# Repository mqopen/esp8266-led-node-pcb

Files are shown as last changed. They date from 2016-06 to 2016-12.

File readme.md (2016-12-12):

# ESP8266 LED Node PCB

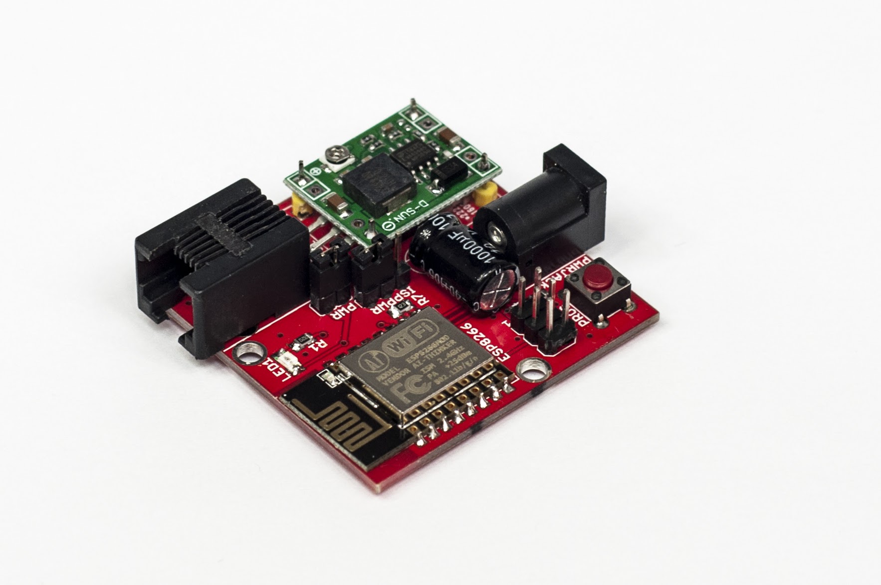
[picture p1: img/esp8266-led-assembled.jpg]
Assembled node


## Features

 - Powered by mini DC-DC power supply module ([LM2596](http://www.ti.com/lit/ds/symlink/lm2596.pdf) chip).
 - 5.5 mm center positive jack.
 - On-board programming connector.
 - Programming push button.
 - Jumper for enabling power supply module.
 - Notification LED.
 - Intended to be manufactured by [dirtypcbs.com](http://dirtypcbs.com/).
 - AVR like ISP header for in circuit programming.
 - MOSFET transistor. 
 - RJ-11 connector for connecting LED strips.

## Images

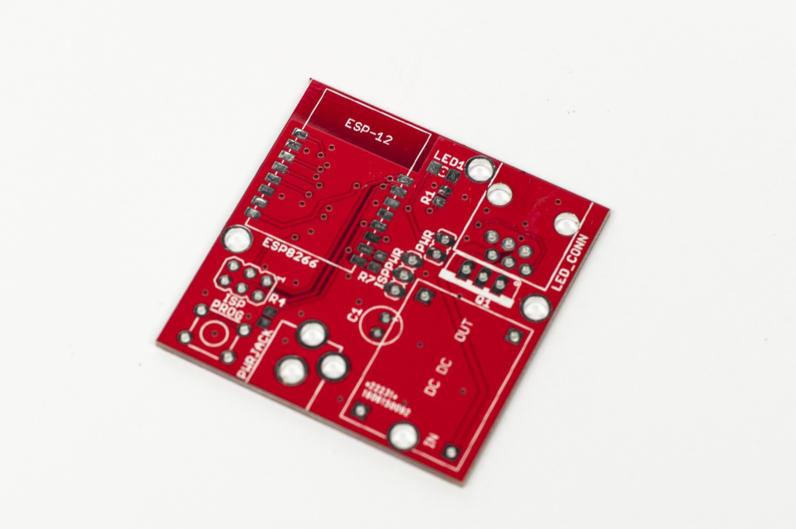
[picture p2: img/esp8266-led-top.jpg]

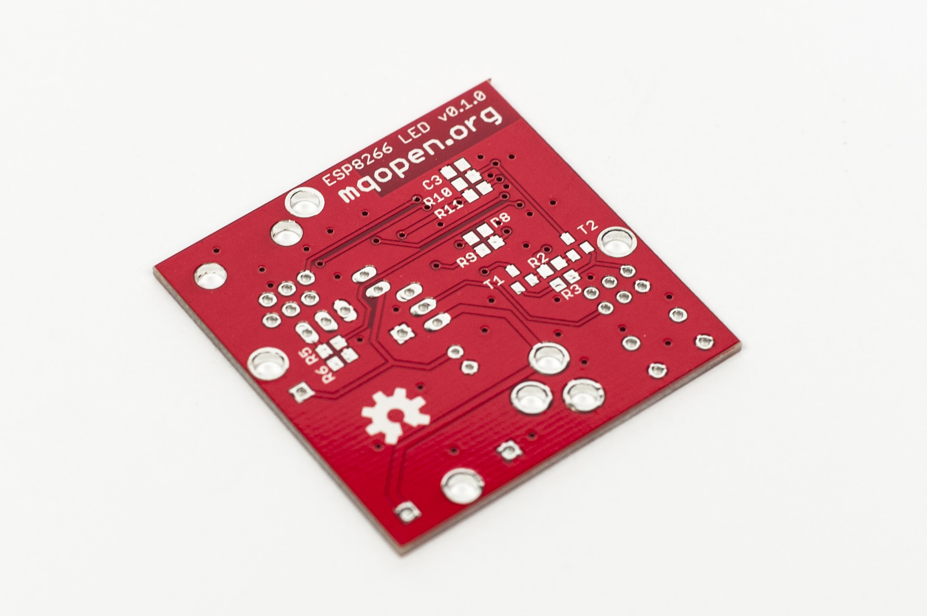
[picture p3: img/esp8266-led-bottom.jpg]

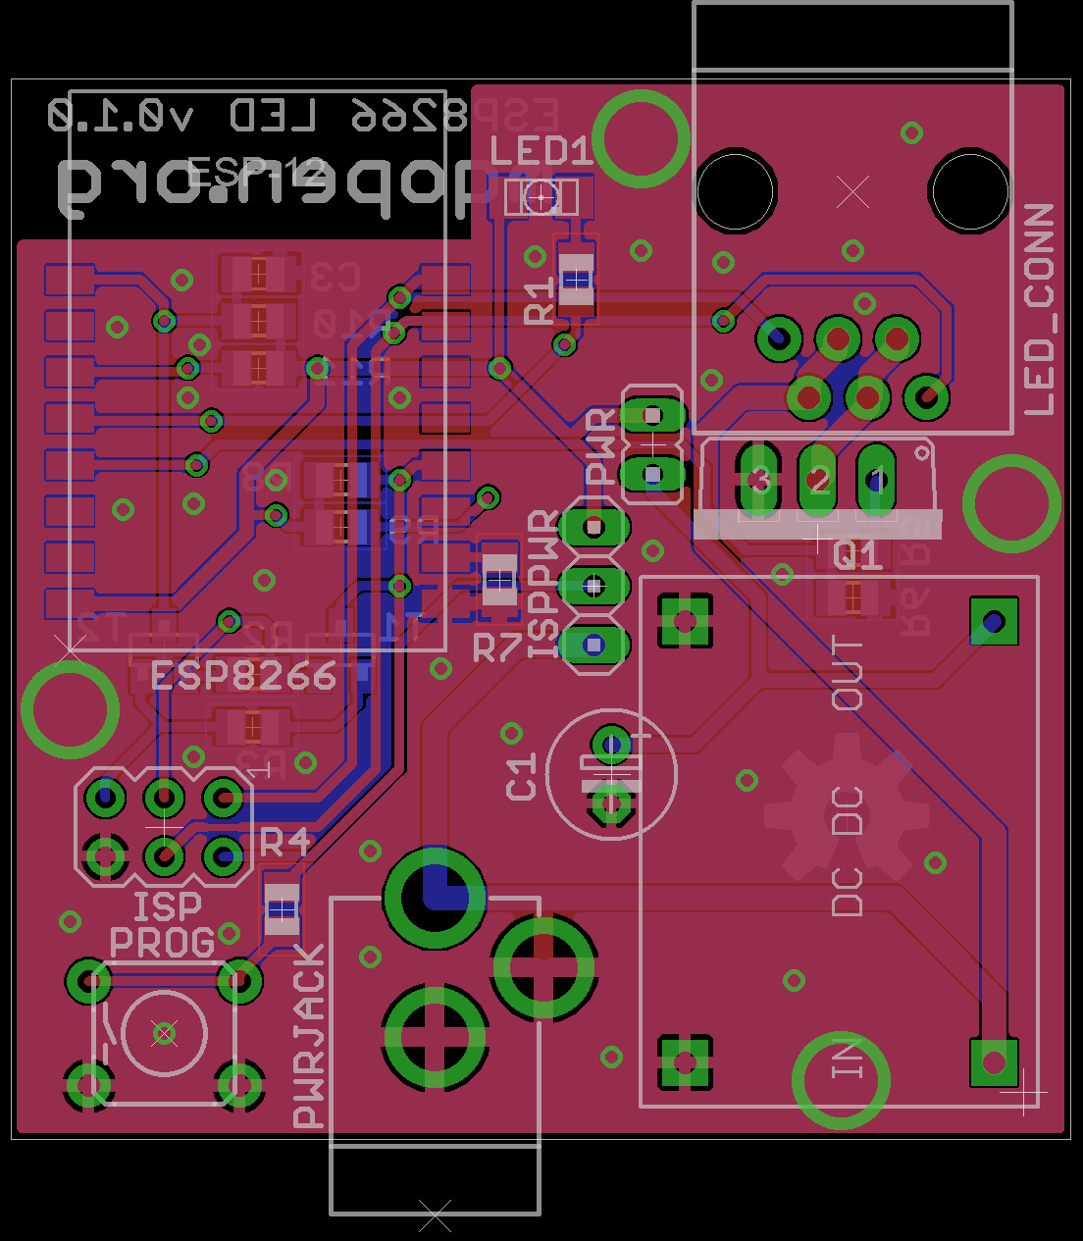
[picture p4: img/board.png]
Board design


## Get board

You can order PCB on this [link](http://dirtypcbs.com/store/designer/details/9988/967/esp8266-led-v0-1-0-zip).

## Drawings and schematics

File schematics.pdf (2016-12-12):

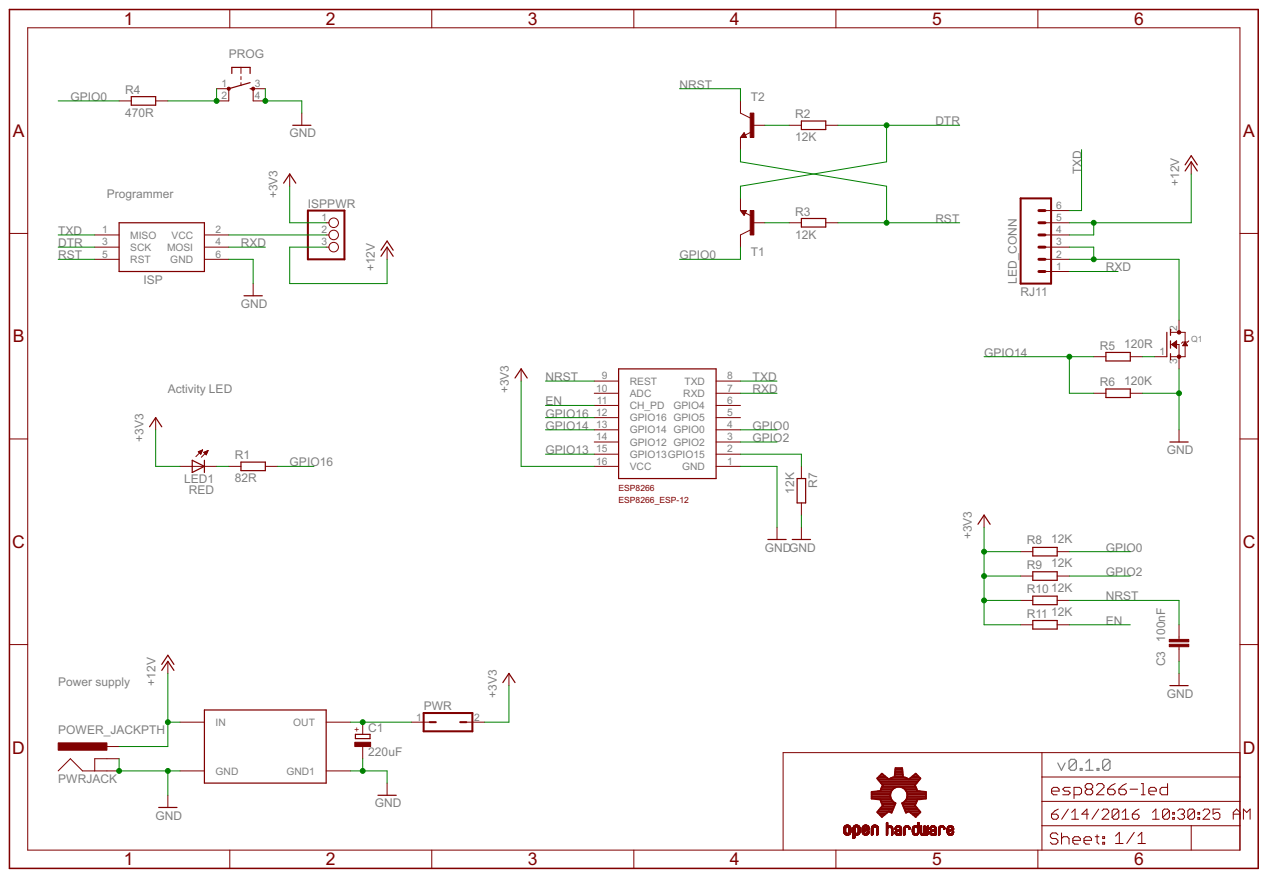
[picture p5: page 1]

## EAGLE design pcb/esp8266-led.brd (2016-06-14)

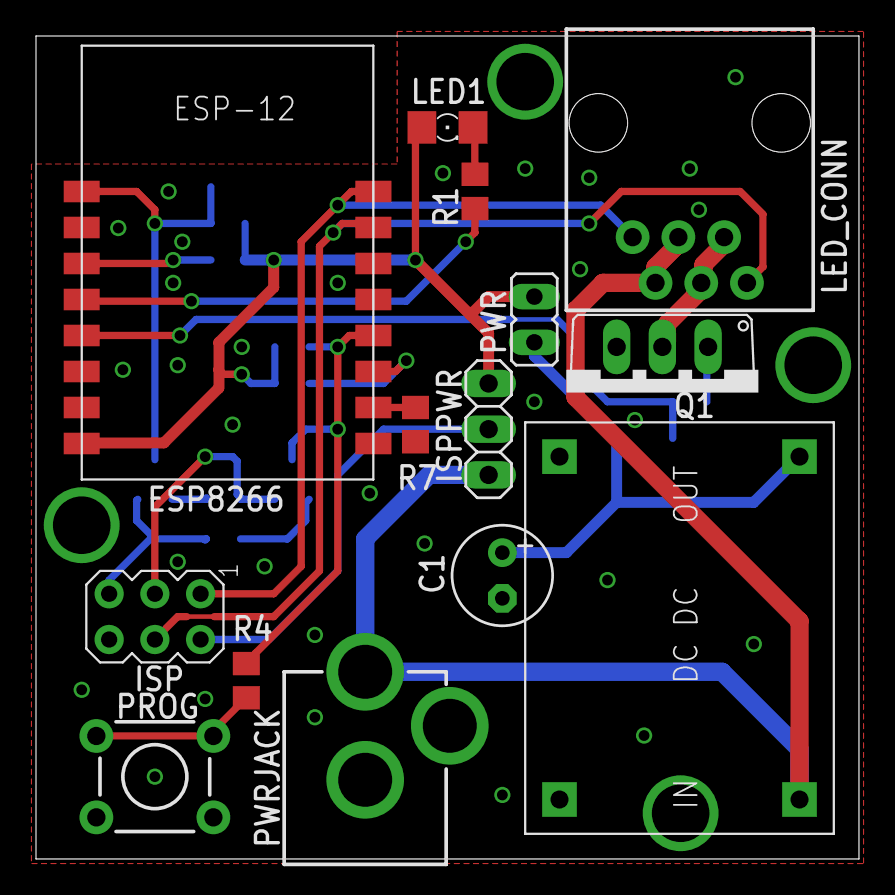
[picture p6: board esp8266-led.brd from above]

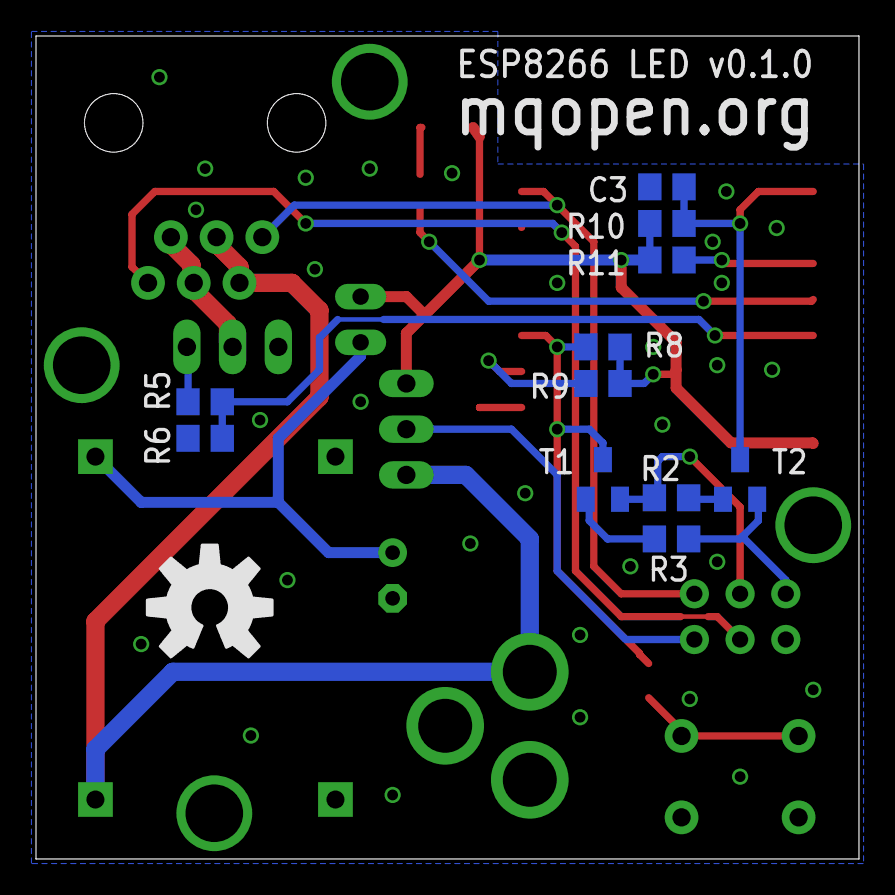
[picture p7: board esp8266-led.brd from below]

Board: 2 copper layers, 45.7 x 45.7 mm, 26 parts (12 on the bottom side), 22 nets.

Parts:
C1: 220uF; E2,5-6
C3: 100nF; C0805
ESP8266: ESP8266_ESP-12; ESP8266-ESP12
ISP: AVRISP-6; AVRISP
ISPPWR: 1X03
LED1: RED; 1206
LED_CONN: RJ11; RJ11-6
PROG: TACTILE-PTH
PWR: JP1
PWRJACK: POWER_JACKPTH; POWER_JACK_PTH
Q1: TO220V
R1: 82R; R0805
R2, R3, R7, R8, R9, R10, R11: 12K; R0805
R4: 470R; R0805
R5: 120R; R0805
R6: 120K; R0805
T1, T2: SOT23-BEC
U$1: OSHW-LOGOL; OSHW-LOGO-L
U$2: DC-DC-SMALL; DC-DC

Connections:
+3V3: ESP8266.16, ISPPWR.1, LED1.A, PWR.2, R8.2, R9.2, R10.2, R11.2
+12V: ISPPWR.3, LED_CONN.4, LED_CONN.5, PWRJACK.PWR, U$2.P$1
DTR: ISP.3, R2.2, T1.E
EN: ESP8266.11, R11.1
GND: C1.-, C3.1, ESP8266.1, ISP.6, PROG.3, PROG.4, PWRJACK.GND, PWRJACK.GNDBREAK, Q1.3, R6.2, R7.2, U$2.P$3, U$2.P$4
GPIO0: ESP8266.4, R4.1, R8.1, T1.C
GPIO2: ESP8266.3, R9.1
GPIO14: ESP8266.13, R5.1, R6.1
GPIO16: ESP8266.12, R1.2
unnamed: LED1.C, R1.1
unnamed: C1.+, PWR.1, U$2.P$2
unnamed: R2.1, T2.B
unnamed: PROG.1, PROG.2, R4.2
unnamed: ESP8266.2, R7.1
unnamed: ISP.2, ISPPWR.2
unnamed: R3.1, T1.B
unnamed: Q1.1, R5.2
unnamed: LED_CONN.2, LED_CONN.3, Q1.2
NRST: C3.2, ESP8266.9, R10.1, T2.C
RST: ISP.5, R3.2, T2.E
RXD: ESP8266.7, ISP.4, LED_CONN.1
TXD: ESP8266.8, ISP.1, LED_CONN.6

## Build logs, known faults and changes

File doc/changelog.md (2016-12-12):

# ESP8266 LED Node changelog

## v0.1.0

 - First board design
 - Powered by mini DC-DC power supply module (LM2596 chip).
 - 5.5 mm center positive jack.
 - On-board programming connector.
 - Programming push button.
 - Jumper for enabling power supply module.
 - ISPPWR jumper.
 - Notification LED.
 - Intended to be manufactured by dirtypcbs.com.
 - AVR like ISP header for in circuit programming.
 - Led driven by N-Channel MOSFET.
 - RJ-11 connector for connecting LED strips.

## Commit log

2016-06-14 Initial commit.
    [esp8266-led.brd, esp8266-led.sch]
2016-06-14 Updated MOSFET dersistor values.
    [esp8266-led.brd, esp8266-led.sch]
2016-12-12 Added board image.
2016-12-12 Added gerber files.
    [esp8266-led.GBL, esp8266-led.GBO, esp8266-led.GBS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]
2016-12-12 Added schematics file.

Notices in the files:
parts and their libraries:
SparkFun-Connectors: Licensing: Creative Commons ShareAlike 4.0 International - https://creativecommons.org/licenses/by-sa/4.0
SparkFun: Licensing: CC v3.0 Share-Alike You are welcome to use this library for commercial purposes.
